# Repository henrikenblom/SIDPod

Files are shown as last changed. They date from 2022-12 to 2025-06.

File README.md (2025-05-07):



_The SIDPod is a PSID player for RP2040 microcontroller based boards, such as the
[Raspberry Pi Pico](https://www.raspberrypi.com/products/raspberry-pi-pico/) or the
[Solder Party RP2040 Stamp](https://www.solder.party/docs/rp2040-stamp/). Playback is based on the SID emulator found in
[Teensy-reSID](https://github.com/FrankBoesing/Teensy-reSID), which in turn is based on
[reSID](https://github.com/daglem/reSID)_

___

<!-- TOC -->
  * [Building](#building)
    * [Software](#software)
      * [Building from source](#building-from-source)
      * [Prebuilt binaries](#prebuilt-binaries)
    * [Hardware](#hardware)
      * [Construction](#construction)
      * [Power](#power)
      * [Bill of materials](#bill-of-materials)
  * [Using](#using)
    * [Finding music](#finding-music)
    * [Creating playlists](#creating-playlists)
    * [Adding music](#adding-music)
    * [Playback](#playback)
      * [Chip support](#chip-support)
      * [Playlist selection](#playlist-selection)
      * [Song selection](#song-selection)
    * [Visualization mode](#visualization-mode)
    * [Volume control](#volume-control)
    * [Pocket mode](#pocket-mode)
    * [Deep sleep](#deep-sleep)
  * [Beta disclaimer](#beta-disclaimer)
    * [General disclaimer](#general-disclaimer)
  * [What's on the horizon?](#whats-on-the-horizon)
<!-- TOC -->

## Building

### Software

#### Building from source

SIDPod requires both the [Raspberry Pi Pico SDK](https://github.com/raspberrypi/pico-sdk/) and the
[pico-extras](https://github.com/raspberrypi/pico-extras). Make sure to grab these and either put them next to the
SIDPod directory or, if you have them somewhere else, point the `PICO_SDK_PATH` and `PICO_EXTRAS_PATH` environment
variables to their respective location. You'll also need CMake on your path. If/when these prerequisites have been
satisfied, you're almost ready to run the `cmake` command to create the build directory and configure the build. One
last thing to do is to make sure the board type matches the one you have. By default, SIDPod builds for the Solder Party
RP2040 Stamp, which, for example, has a larger NAND flash than the more common Raspberry Pi Pico. Using a RP2040 Stamp
UF2 on a Pi Pico would most likely cause issues on the first run, as the flash will get formatted, **using board
specific settings**, if no readable FAT filesystem is found on it. Changing board type can either be done by modifying
the `PICO_BOARD` variable in [CMakeLists.txt](CMakeLists.txt) or by setting the `PICO_BOARD` environment variable before
running the `cmake` commands. The correct value for the Raspberry Pi Pico is 'pico'. Once this is done, the build is
configured by running:

`cmake -B cmake-build-debug`

Alternatively, if you have [Ninja](https://ninja-build.org/) installed, you can save a few seconds of your valuable time
by instead running:

`cmake -G Ninja -B cmake-build-debug`

Then, to build the _SIDPod.uf2_ binary, issue:

`cmake --build cmake-build-debug --target all`

Once the build finishes, just follow the official instructions for loading a UF2 binary onto the board. For Raspberry Pi
Pico you hold down the _BOOTSEL_ button when you plug it in and then copy _SIDPod.uf2_ to it, once it appears as a
drive named _RPI-RP2_. For some other types of boards, such as the Solder Party RP2040 Stamp, this mode is activated by
double-clicking the reset button.

Also note that if you're running macOS, copying using Finder might fail with this
error: _The operation can’t be completed because an unexpected error occurred (error code 100093)._
If this is the case, fire up the 'ol terminal and do:

`cp cmake-build-debug/SIDPod.uf2 /Volumes/RPI-RP2`

#### Prebuilt binaries

To get a jump start you can also grab the [prebuilt binaries](https://github.com/henrikenblom/SIDPod/releases/latest).
There are two versions, one for the Solder Party RP2040 Stamp and one for the Raspberry Pi Pico.

### Hardware

#### Construction

Since the main goal is to make a portable player, the actual build and design is up to you, the maker. My current
prototype is built inside a 3-AA battery box I had lying around, using a Solder Party RP2040 Stamp and a 3.7V 150mAh
LiPo battery. However, the breadboard design I'm using for development, based on a Raspberry Pi Pico H, looks like this:

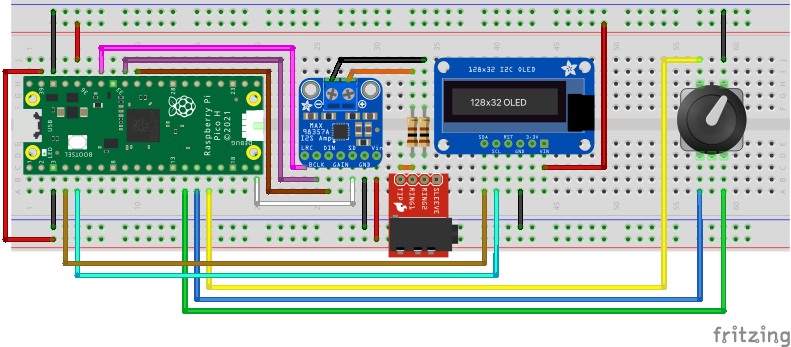
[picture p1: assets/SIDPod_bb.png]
  
_The breadboard schematics._

In reality, the development breadboard looks a bit different. I use a dual lane breadboard and connect to the SIDPod
Pico board via a [Picoprobe](https://github.com/raspberrypi/picoprobe), for debugging and a less painful development
process.

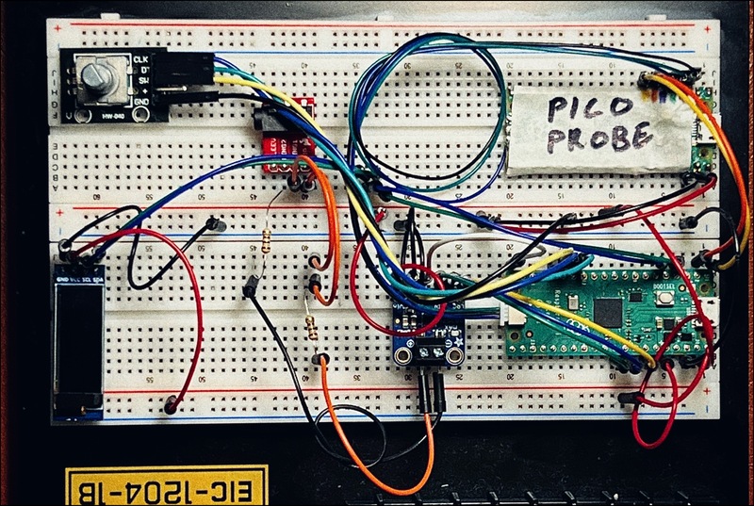
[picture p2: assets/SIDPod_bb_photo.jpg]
  
_The development breadboard setup._

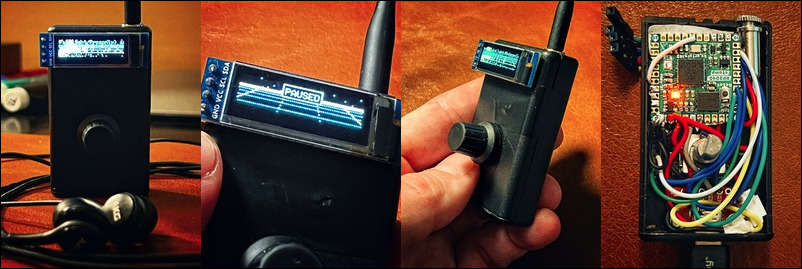
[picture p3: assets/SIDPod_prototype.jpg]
  
_The working prototype. Please excuse the soldering. I'm a lover, not a solderer. 😜_

#### Power

The main advantage of the Solder Party RP2040 Stamp, besides its size, is the onboard LiPo charger. This removes some
complexity and saves space when moving beyond the breadboard design. Many RP2040 projects can easily run off the power
provided from the host computer over the built-in USB port. The SIDPod however, will enter a special USB device state
and start to mimic a USB mass storage device once connected to a computer. [More on that here](#adding-music). This
poses a problem, if you actually want to use it for what it's designed for - to play PSIDs. That problem can easily be
solved by powering it from any power source connected to the _VSYS_ pin. That power source can be anything from a 3.7V
LiPo battery to a separate USB breakout bord, with the breakout boards _VBUS_ connected to _VSYS_ on the Pico Board and
the breakout board GND connector connected to any GND on the Pico Board. In my development breadboard setup I power the
SIDPod Pico Board from the Picoprobe Pico Board. In the next section I've listed the components needed for a few
different options:

#### Bill of materials

_Option 1 - Using a Solder Party RP2040 Stamp (the prototype setup):_

- 1 x [Solder Party RP2040 Stamp](https://www.electrokit.com/en/product/rp2040-stamp/)
- 1 x [Adafruit I2S 3W Class D Amp - MAX98357A](https://www.electrokit.com/en/product/forstarkare-klass-d-3w-mono-i2s/)
- 1 x [LCD OLED 0.91″ 128x32px I2C](https://www.electrokit.com/en/product/lcd-oled-0-91-128x32px-i2c/)
- 1 x 3.5mm stereo jack
- 1 x [Rotary encoder w switch](https://www.electrokit.com/en/product/rotary-encoder-module/)
- 2 x [100Ω resistor](https://www.electrokit.com/en/product/resistor-1w-5-100ohm-100r/)
- 1 x [Battery LiPo 3.7V 150mAh](https://www.electrokit.com/en/product/batteri-lipo-3-7v-150mah/)

_Option 2 - Using a Raspberry Pi Pico (the breadboard setup):_

- 1 x [Adafruit I2S 3W Class D Amp - MAX98357A](https://www.electrokit.com/en/product/forstarkare-klass-d-3w-mono-i2s/)
- 1 x [LCD OLED 0.91″ 128x32px I2C](https://www.electrokit.com/en/product/lcd-oled-0-91-128x32px-i2c/)
- 1 x [3.5mm stereo jack](https://www.electrokit.com/en/product/3-5mm-jack-breakout-2/)
- 1 x [Rotary encoder w switch](https://www.electrokit.com/en/product/rotary-encoder-module/)
- 2 x [100Ω resistor](https://www.electrokit.com/en/product/resistor-1w-5-100ohm-100r/)

_Option 2a - Add a Raspberry Pi Pico with Picoprobe, for debugging, binary upload and power through VSYS:_

- 2 x [Raspberry Pi Pico H](https://www.electrokit.com/en/product/raspberry-pi-pico-h/)

_Option 2b - Power the Raspberry Pi Pico through a USB breakout board:_

- 1 x [Raspberry Pi Pico H](https://www.electrokit.com/en/product/raspberry-pi-pico-h/)
- 1 x [Breakout board USB-C](https://www.electrokit.com/en/product/anslutningskort-usb-c/)

## Using

To keep the construction as simple as possible I tried to minimize the number of physical controls, and a rotary encoder
with a built-in push button provides enough versatility to cater to every possible use case of this rather minimal
design. Therefore, controls are both contextual and pattern driven.

### Finding music

The [SID or Sound Interface Device](https://en.wikipedia.org/wiki/MOS_Technology_6581), which this player does a
rudimentary emulation of, was a component in the world's most popular home computer, the
[Commodore 64](https://en.wikipedia.org/wiki/Commodore_64). Due to its legendary status and, to this day, very active
community, there's no shortage of SID files to fill your SIDPod with. The most complete collection is the
[High Voltage SID Collection](https://www.hvsc.c64.org/). It has everything, from cult classics by the legendary Jeroen
Tel to contemporary pieces by Kamil Wolnikowski, aka Jammer. Download the full archive and use one of the SID players
referenced on that page to find the music you like. The collection contains both PSIDs and RSIDs. Most PSIDs are
playable and with the introduction of reSID, (version 2.0beta and later) some RSIDs are playable. However, full
compatibility is not guaranteed yet. _This is being worked on though._

### Creating playlists

With the introduction of version 2.0beta, **music must be put in playlists**. And the definition of a playlist is a
folder with at least one PSID in it. Furthermore, to avoid out of memory errors, the maximum number of PSIDs in a
playlist is restricted to 256. And the number of playlists is limited to 256 as well. This means that the maximum number
of PSIDs is 65536. Coincidentally, the memory size of our favorite 8-bit home computer. ❤️

_As you may have figured out, this many PSIDs would never fit on the internal flash. They will however fit on a
standard size SD card, which is something that will be supported when SIDPod 2.0 is out of beta._

### Adding music

The SIDPod doubles as a USB mass storage device, which means that if you plug it in to your computer it will show up as
a regular, FAT-formatted drive. This means that adding and removing PSIDs is as easy as copying or deleting files. There
are a few caveats though:

- Since version 2.0beta PSIDs must be put in folders. As mentioned above.
- Use it with moderation. [FatFs](http://elm-chan.org/fsw/ff/00index_e.html) doesn't have any
  [wear levelling algorithm](https://en.wikipedia.org/wiki/Wear_leveling), and NAND flash storage wears out faster than
  regular flash drives. Note though that this only goes for write operations. Reading is totally harmless.
- It's slower than you're probably used to. This is due to several factors. One being that flash memory blocks needs to
  be erased before new data can be written to them.

While the SIDPod is connected, the screen shows flickering bars. Don't be alarmed. This is a feature, not a bug. In
fact, it's a reference to the C64 - those who know, know.

### Playback

#### Chip support

Since the introduction of version 2.0beta, the SIDPod supports both the MOS 6581 and MOS 8580 chip models, and up to
three SID chips. There's no need to worry about which chip is used in the PSID file, or how many, as the SIDPod will
automatically detect this and set up the emulation accordingly.

_Disclaimer: Some 3-SID songs are a bit too much for the poor SIDPod, resulting in partial stutter when the filters are
active. Unless you overclock it! Currently, the clock speed is set to 200MHz, which is the highest officially supported
setting. For songs like Melbourne Shuffle by Jammer, you need to stretch this all the way up to 260. Which might damage
your microcontroller!_

#### Playlist selection



Once you've added some funky tunes and **safely disconnected** the SIDPod it presents the playlists. In alphabetical
order. The controls in this mode are:

- Scroll through the list by turning the encoder.
- Single-clicking enters the selected playlist.

If you've started a song, as described in the next section, the relevant playlist is decorated with an animated spectrum
analyser symbol. When a song is paused, the animation is paused as well.

#### Song selection



Once you've entered a playlist, the screen shows the songs in that playlist. Also in alphabetical order. There's also a
*<< Return* entry at the top. Use it to navigate back to the playlist selection view. The controls in this mode are:

- Scroll through the list by turning the encoder.
- Single-clicking plays the selected song and enters a very retro-fancy visualization mode.
- Double-clicking plays or pauses the selected song but keeps the playlist mode.
- Double-clicking in visualization mode pauses playback and displays a pause notification on screen.

The currently selected song is decorated with a traditional play symbol and the currently playing song is decorated with
an animated spectrum analyser symbol. When a song is paused, the animation is paused as well.

If a song gets crossed out when you're trying to play it, it means that it's either corrupt or uses a combination of
opcodes that have caused the song loading routine to enter an infinite loop and seemingly hang. This is very rare for
PSIDs, but unfortunately a little more common for RSIDs. _As mentioned above, a fix for this is being worked on._

### Visualization mode



This is the mode that shows the animated spectrum analyser. _Plus a few other effects._ The controls in this mode are:

- Single-clicking returns to the song selection view.
- Double-clicking plays or pauses the selected song but keeps the visualization mode.
- Turning the encoder adjusts the volume. See below.

### Volume control



This control is only available from the visualization mode and is activated by rotating the encoder. Turn the encoder
clockwise to increase the volume and counter-clockwise to decrease it. The current volume is displayed on screen as long
as the encoder is being turned. Plus 400ms after the last turn.

_Warning! With the current implementation the overall sound volume has increased since the first version. Be mindful of
this, if you're using headphones._

### Pocket mode

In this mode the screen is turned off, as well as the regular controls. Playback is still active though, which makes it
perfect for when you're out and about. To enter this mode, simply hold the button pressed until the screen goes black.
This takes exactly one second. Be careful not to hold it for too long, as this will put the SIDPod to sleep. More on
that in the next section. To get out of pocket mode, simply double-click, and it will return to whatever mode you were
in before entering pocket mode.

### Deep sleep

This mode is as close as you can get to turning the SIDPod off. As with pocket mode, all regular controls are disabled.
Additionally, playback is stopped, as well as USB device clocks. In fact, in this mode, even both processor cores are
stopped, meaning that the power consumption is next to nothing. To enter deep sleep, press the button for more than two
and a half second. To get out, hold the button until the SIDPod splash appears.

## Beta disclaimer

This is a beta version of the SIDPod. While it has been tested thoroughly, there are still some bugs and issues that
need to be worked out. And the entire code base would benefit from some cleanup and pattern alignment.

### General disclaimer

Even though I am a professional software engineer, I am a novice and a hobbyist when it comes to both hardware and C/C++
development. So there's a good chance that I have made more than a few mistakes. If you find any, please let me know, by
opening an issue on GitHub. I'll be happy to fix them and learn from them. Hopefully in a timely manner.

## What's on the horizon?

- Support for SD cards. This will allow you to store a lot more music than the internal flash can handle.
- Pi Pico 2 support. This will improve performance and playback quality. Potentially, this could allow for builtin
Bluetooth A2DP support. For Pi Pico 2W boards.
- "SIDPod Buddy" support. The SIDPod Buddy is an ESP32 based device that allows you to control the SIDPod using a
Cirque TM023023 Trackpad. Additionally, it provides Bluetooth A2DP support, which means that you can stream music to any
Bluetooth enabled speaker.
- A custom PCB, incorporating all the components needed to make a fully functional SIDPod. With SIDPod Buddy support.

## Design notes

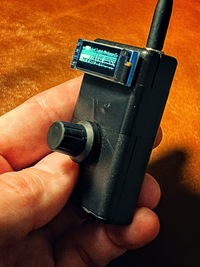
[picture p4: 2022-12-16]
assets/SIDPod_photo_4.jpg

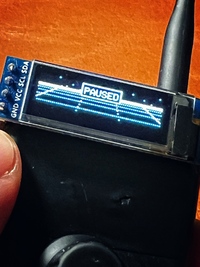
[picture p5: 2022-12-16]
assets/SIDPod_photo_2.jpg

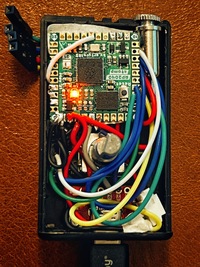
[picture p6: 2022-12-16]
assets/SIDPod_photo_3.jpg

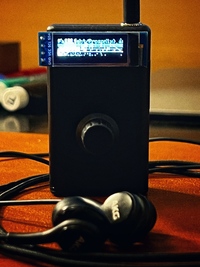
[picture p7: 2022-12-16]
assets/SIDPod_photo_1.jpg

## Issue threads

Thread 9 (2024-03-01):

Stuck on PAUSED

LouDnl, 2024-03-01:
Hi there, great project! I have an issue where the device will never leave PAUSED.
Everything seems to work and be connected correctly, display works, rotary works, can set volume choose song etc.
But the double click seems to not do anything

I am using your pre compiled PICO binary.

LouDnl, 2024-03-01:
Its not the doubleclick I think, it just will not play any sid. Locked specifically for psid files. They show and I can select them, but then its paused immediately

LouDnl, 2024-03-01:
After compiling myself it unfortunately still did not work.
Tried debugging with gdb but was missing debug symbols. Recompiled with debugsymbols and used the elf with gdb but didnt works, forgot to flash the new compiled version.

As soon as I flashed the compiled bin and started gdb everything worked without doing anything 🤷🏻‍♂️

Still don't know what fixed it 🤣

LouDnl, 2024-03-01:
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

MaoCiao7, 2025-04-24:
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

Would you please share your forked binary? :) I tried the prebuilt from henrikenblom, but have the same problems.

henrikenblom, 2025-04-24:
Hey there! First of all, it warms my heart that people are building their own SIDPods! Secondly, I apologize for my lack of activity and engagement. And lastly, I decided to give this project some love, by:

- fixing bugs
- integrating reSID (with tripple-SID support)
- adding SD-card support
- adding playlist support

This all lives in the 'resid' branch (please note that the I2S pins for the display is different in that branch, if you decide to try it out). But since you're here due to bugs, I'll try to find some time in the next few days to fix the most critical ones in the master branch as well. And I'll make sure to keep you posted.

henrikenblom, 2025-05-07:
Hello again, @MaoCiao7 et al. I've put together a pre-release - version 2.0beta. Give it a try!
https://github.com/henrikenblom/SIDPod/releases

MaoCiao7, 2025-05-08:
Hi @henrikenblom,

thank you very much! I've only been able to test a little so far, but it works much better now! Music is coming to the headphones and the navigation is also working. However, only 2 or 3 PSIDs (out of about 10) that I randomly selected for the test also had sound. Maybe I was just unlucky here in terms of compatibility. When there was sound, it was unfortunately not flawless. It seems that not all channels are equally loud and the sounds are generally distorted. Slow CLK issue? For the not working files, the small play animation appears next to the file name in the song selection screen, but otherwise it remains completely silent. In the Visualization Screen, the visual effects are also missing for those files, in line with the non-existent music, but the text is displayed.
I´ll try more songs as soon as possible.

henrikenblom, 2025-05-09:
> When there was sound, it was unfortunately not flawless. It seems that not all channels are equally loud and the sounds are generally distorted. Slow CLK issue?

This sounds to me like an issue with the amplifier. The hardware setup I've described is a workaround for the lack of I2S headphone amplification breakout boards on the market. - The two resistors between the amp and the headphones are put there to compensate for the difference in impedance specification between headphones and "regular" speakers. But this is basically a very crude hardware hack, that might not work for all headphones. So, could you try to remove the resistors and use a small 2-5W rated speaker instead, to see if the problem persists? If you're using the exact amp model described in the setup, there's also a gain setting to play around with.

> However, only 2 or 3 PSIDs (out of about 10) that I randomly selected for the test also had sound.

Could you post the names, (and artists) of some of the PSIDs that didn't work? So that I can check wether it's due to any of the known issues.

MaoCiao7, 2025-05-09:
you were right, the distortion was caused by my headphones. I tried my other headset and it sounds clean now. songs with no sound are eg. from Chris Huelsbeck, To be on top & Being boild.

henrikenblom, 2025-05-09:
My suspicions regarding Ikari Warriors were correct. And I've merged a small fix for it. It turned out to be an unfortunate, and somewhat exotic, combination of a high CIA Timer value and NTSC. So even if it would have played, the tempo would have been completely off.

New release here: https://github.com/henrikenblom/SIDPod/releases/tag/v2.0.1beta

Btw, I'm closing this issue now, since it no longer has anything to do with the original one. But feel free to open new one's at any time.

Closed 2025-05-09.

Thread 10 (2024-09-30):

Sidpod building

n2hyo, 2024-09-30:
Hello there, i have build a sidpod on a breadboard and it seems to work but i am not getting any audio output
when i select a song and the click on it, it goes paused another press goes out of pause, i never get any indication
that the song is actually playing and by the way i am using the prebuild image. Does a pal/ntsc sid have any bearing
on ability to be played?

Thank You,
Mike Russell

Neril, 2024-10-10:
@n2hyo

I'm not an author / contributor to this project but coincidentally this week I successfully managed to get SIDPod working on my own breadboard. Given your issue was reported last week, maybe I can help.

Just a random punt, but if you're getting a play indication next to your SID files and/or wave forms being shown in the visualiser, I think the issue must lie with your amp / amp wiring, or downstream of that.

Feel free to post a picture / video of your board and tag me and if I see it then I'll compare it to mine while I still have it assembled.

n2hyo, 2024-10-10:
Hello Neril, no i never get the wave forms in thew visualizer, i know it will only play psid files which i think i have but may be the problem. I have attached the file i am trying to play maybe you can try it and maybe send me back a sid file you know works on yours.

Thanks Mike
[Ashes_to_Ashes.zip](https://github.com/user-attachments/files/17334544/Ashes_to_Ashes.zip)

Neril, 2024-10-10:
The ashes to ashes entry doesn't show up in the SIDPod list for me after I add the file. I think this is likely because the SIDPod code recognises it as something it can't play. I'm not immediately sure why - it has the PSID header (first 4 bytes), but there's a long and storied history around SID files and versioning I've only scratched the surface of, so it may be a variant of the format it doesn't recognise / can't handle.

I've been getting my .sid files out of HVSC_81-all-of-them.7z from https://www.hvsc.c64.org/downloads
I notice it contains Ashes_to_Ashes.sid under MUSICIANS/L/Linus, and it looks the same as the version you attached (i.e. same file size). A_mouse_me_kitty.sid from the same directory worked for me, though. I've personally been testing with Wizball.sid (Gallway_Martin) and most of Rob Hubbard's work (e.g. The Master of Magic) which work well besides a few volume issues.

It's a long shot, but I initially had problems getting playback to start initially. I tracked it down and wrote a long ramble about it here https://github.com/henrikenblom/SIDPod/issues/9

n2hyo, 2024-10-11:
So i loaded that song you mentioned and when i plug the pico into usb port the

https://github.com/user-attachments/assets/c2af47bf-28c7-407e-bdbf-805afa5f97cf

screen does this, is this supposed to be playing?

Neril, 2024-10-12:
Those lines are what SIDPod displays when it has noticed it is plugged into a PC, so it's emulating a USB flash drive and ready to accept SID files. What you are seeing is the "flashing bars" described at https://github.com/henrikenblom/SIDPod?tab=readme-ov-file#adding-music - reminiscent of a game C64 loading screen.

To get SIDPod into a mode where it will play tunes it needs to be _not_ connected to a PC. This is most easily achieved by taking your USB cable out of your PC and putting it into a spare phone charger or USB battery. The SIDPod will boot up, showing the SIDPod logo like before, but then showing the list of songs you've stored on the device instead of the flashing bars. Playing music is achieved via steps documented at https://github.com/henrikenblom/SIDPod?tab=readme-ov-file#playback

TBH, I thought you'd got this far from your original comment above.

Closed 2025-05-12.

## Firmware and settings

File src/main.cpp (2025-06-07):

// ReSharper disable once CppUnusedIncludeDirective
#include <hardware/clocks.h>
#include <device/usbd.h>
#include <hardware/watchdog.h>
#include "platform_config.h"
#include "audio/SIDPlayer.h"
#include "UI.h"
#include "System.h"
#include "Catalog.h"

using namespace std;

void buddyCallback();

void runPossibleSecondWakeUp() {
    if (watchdog_caused_reboot()) {
        int c = 0;
        while (c++ < LONG_PRESS_DURATION_MS) {
            if (gpio_get(SWITCH_PIN)) {
                System::goDormant();
            }
            busy_wait_ms(1);
        }
    }
}

bool awaitButtonRelease() {
    int c = 0;
    while (!gpio_get(SWITCH_PIN)) {
        busy_wait_ms(1);
        c++;
    }
    return c >= LONG_PRESS_DURATION_MS;
}

#if USE_BUDDY
void initUart() {
    uart_init(UART_ID, 2400);

    gpio_set_function(UART_TX_PIN, UART_FUNCSEL_NUM(UART_ID, UART_TX_PIN));
    gpio_set_function(UART_RX_PIN, UART_FUNCSEL_NUM(UART_ID, UART_RX_PIN));

    uart_set_baudrate(UART_ID, BAUD_RATE);
    uart_set_hw_flow(UART_ID, false, false);
    uart_set_format(UART_ID, DATA_BITS, STOP_BITS, PARITY);
    uart_set_fifo_enabled(UART_ID, true);

    irq_set_exclusive_handler(UART1_IRQ, buddyCallback);
    irq_set_enabled(UART1_IRQ, true);

    uart_set_irq_enables(UART_ID, true, false);
}
#endif

[[noreturn]] int main() {
    set_sys_clock_khz(CLOCK_SPEED_KHZ, true);
    stdio_init_all();
#if USE_BUDDY
    initUart();
#endif
    UI::initUI();
    runPossibleSecondWakeUp();
    UI::screenOn();
    UI::showSplash();
    UI::screenshotToPBM();
    const bool quickStart = awaitButtonRelease();
    System::enableUsb();
    if (!System::usbConnected()) {
        System::prepareFilesystem();
        UI::start(quickStart);
        SIDPlayer::initAudio();
    }
    while (true) {
        UI::updateUI();
    }
}
#pragma clang diagnostic pop

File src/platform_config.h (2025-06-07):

#pragma once

#define IS_BIT_SET(value, bit) (((value) & (1 << (bit))) != 0)

#ifndef USE_SDCARD
#include "hardware/flash.h"

#ifdef SOLDERPARTY_RP2040_STAMP
#define FLASH_STORAGE_BYTES (7552 * 1024)
#endif
#ifdef RASPBERRYPI_PICO
#define FLASH_STORAGE_BYTES                 (1408 * 1024)
#endif

#define SECTOR_COUNT                        (FLASH_STORAGE_BYTES / FLASH_SECTOR_SIZE)
#define FLASH_BASE_ADDR                     (PICO_FLASH_SIZE_BYTES - FLASH_STORAGE_BYTES)
#define FLASH_MMAP_ADDR                     (XIP_BASE + FLASH_BASE_ADDR)

#endif

#define AIRCR_Register                      (*((volatile uint32_t*)(PPB_BASE + 0x0ED0C)))
#define SYSRESETREQ                         0x5FA0004

#if defined SYS_CLK_MHZ && SYS_CLK_MHZ == 200
#define CLOCK_SPEED_KHZ                     200000
#else
#define CLOCK_SPEED_KHZ                     125000
#endif

#define SYNC_INTERVAL_MS                    40

#define BOARD_TUD_RHPORT                    0

#ifndef HW_USB_VID
#define HW_USB_VID                          (0x2E8A)
#endif
#ifndef HW_USB_PID
#define HW_USB_PID                          (0x0006)
#endif

#define FS_LABEL                            "SIDPOD"

#define AUDIO_RENDERING_STARTED_FIFO_FLAG   124

#define PSID_HEADER_SIZE                    ((uint8_t) 0x7e)
#define PSID_MINIMAL_HEADER_SIZE            ((uint8_t) 0x56)
#define PSID_ID                             0x50534944
#define RSID_ID                             0x52534944
#define SID_LOAD_BUFFER_SIZE                ((int) 256)
#define CPU_JSR_WATCHDOG_ABORT_LIMIT        0xffff

#define SAMPLE_RATE                         ((uint32_t)44100)
#define MAX_SAMPLES_PER_BUFFER              880
#define PAL_SPEED_FACTOR                    1.0f
#define NTSC_SPEED_FACTOR                   0.96f
#define NTSC_CPU_FREQUENCY                  1022730
#define PAL_CPU_FREQUENCY                   985248

#define AMP_CONTROL_PIN                     15

#define VOLUME_STEPS                        48
#define INITIAL_VOLUME                      16
#define SONG_SKIP_TIME_MS                   5000

#define I2C_BAUDRATE                        400000
#define DISPLAY_I2C_BLOCK                   i2c1
#define DISPLAY_GPIO_BASE_PIN               2
#define DISPLAY_EXTERNAL_VCC                0
#define DISPLAY_WIDTH                       128
#define DISPLAY_HEIGHT                      32
#define DISPLAY_X_CENTER                    (DISPLAY_WIDTH / 2)
#define DISPLAY_Y_CENTER                    (DISPLAY_HEIGHT / 2)
#define DISPLAY_I2C_ADDRESS                 0x3C

#define UART_ID                             uart1
#define BAUD_RATE                           115200
#define UART_TX_PIN                         8
#define UART_RX_PIN                         9
#define DATA_BITS                           8
#define STOP_BITS                           1
#define PARITY                              UART_PARITY_NONE

#define DISPLAY_STATE_CHANGE_DELAY_MS       500
#define FONT_WIDTH                          6
#define FONT_HEIGHT                         8
#define LIST_WINDOW_SIZE                    (size_t)((DISPLAY_HEIGHT / FONT_HEIGHT) - 1)
#define MAX_PATH_LENGTH                     FF_LFN_BUF + FF_SFN_BUF + 1
#define MAX_LIST_ENTRIES                    256
#define RETURN_ENTRY_TITLE                  "<< Return"
#define SONG_LIST_LEFT_MARGIN               6
#define NOW_PLAYING_SYMBOL_HEIGHT           5
#define NOW_PLAYING_SYMBOL_ANIMATION_SPEED  ((float) 0.1)
#define DEFAULT_SPECTRUM_COMPENSATION       ((double ) 0.00002)
#define LINE_LEVEL_SPECTRUM_COMPENSATION    ((double ) 0.00000003)
#define HORIZONTAL_LANDSCAPE_LINES          (DISPLAY_HEIGHT / 2)
#define SOUND_SPRITE_COUNT                  (DISPLAY_HEIGHT * DISPLAY_WIDTH / 8)
#define ROUND_SPRITE_COUNT                  (DISPLAY_WIDTH / 2)
#define STARFIELD_SPRITE_COUNT              (int (DISPLAY_WIDTH * 3))
#define SPECTRUM_SCENE_DURATION_MS          62000
#define ALTERNATIVE_SCENE_DURATION          79000
#define STARFIELD_ACTIVE_AFTER              30000
#define END_SPHERE_SCENE_AFTER              35000
#define FROM_ALTERNATIVE_TRANSITION_DURATION       8600
#define SCROLL_LIMIT                        (-1000)
#define FFT_SAMPLES                         1000
#define LOW_FREQ_DOMINANCE_COMP_OFFSET      2
#define SIDPLAYER_STARTUP_GRACE_TIME        800
#define SONG_NUMBER_DISPLAY_DURATION        3000
#define SONG_NUMBER_SHOW_HIDE_DURATION      1000
#define SONG_NUMBER_DISPLAY_DELAY           1000

#define USER_CONTROLS_POLLRATE_MS           50

#if (!USE_BUDDY)
#define ENC_PIO                             pio1
#define ENC_SM                              1
#define ENC_BASE_PIN                        10
#endif

#define SWITCH_PIN                          12
#define DOUBLE_CLICK_SPEED_MS               250
#define LONG_PRESS_DURATION_MS              1000
#define DORMANT_ADDITIONAL_DURATION_MS      1500
#define VOLUME_CONTROL_DISPLAY_TIMEOUT      400
#define SPLASH_DISPLAY_DURATION             2000
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

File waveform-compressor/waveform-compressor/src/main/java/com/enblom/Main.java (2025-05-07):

package com.enblom;

import java.io.IOException;
import java.nio.file.Path;

public class Main {

  public static void main(String[] args) {
    Compressor compressor = new Compressor();
    try {
      var compressed =
          compressor.compress(
              Path.of(
                  "/Users/henblom/projects/github/henrikenblom/SIDPod/src/audio/reSID/wave6581_PST.cc"));
      for (int i = 0; i < 64; i++) {
        if (i % 16 == 0) {
          System.out.println();
        }
        System.out.print(String.format("0x%02x, ", compressed.values.get(i)));
      }
      System.out.println();
      System.out.println();
      System.out.println(compressed);
      for (int i = 0; i < 4096; i++) {
        if (i % 8 == 0) {
          System.out.print(String.format("\n/* 0x%03x: */  0x%02x, ", i, compressed.getValue(i)));
        } else {
          System.out.print(String.format("0x%02x, ", compressed.getValue(i)));
        }
      }
    } catch (IOException e) {
      e.printStackTrace();
    }
  }
}

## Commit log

2022-11-15 Add song selection using an encoder
2022-11-15 Fix broken USB connection handling
    Show raster bars when connected to host
    [UI.cpp, main.cpp]
2022-11-17 Avoid I2S external race conditions when switching songs
    [UI.cpp, main.cpp, sid.c]
2022-11-17 Increase song switch stability
    [UI.cpp]
2022-11-17 Reduce switch glitching
2022-11-18 Reset core1 on USB mount
    [main.cpp]
2022-11-18 Ignore i2c ack errors during flash writes
    [UI.cpp]
2022-11-18 Move the entire audio stack to core1
    Reset the entire machine on USB disconnect
    [UI.cpp, main.cpp]
2022-11-21 Use the AIRCR to request the post USB suspend reset
    [main.cpp]
2022-11-21 Reduce encoder read flakiness by using PIO
2022-11-21 Reduce memory footprint
    Fix tempo issue
2022-11-21 Revert CIA sync changes
    [main.cpp]
2022-11-21 Add TODO on something that needs to be fixed in order to reduce footprint
2022-11-22 Reduce PSIDCatalog footprint
2022-11-23 Add support for I2S amp shutdown/powerup
    Cleanup
2022-11-26 Trigger volume control by encoder
    Time limit volume control session
2022-11-26 Enable navigation to and from visualization of current song and list view
2022-11-26 Add power save functions
2022-11-27 Freeze pause screen to conserve power
2022-12-01 Make the Solderparty RP2040 Stamp the default config
    Decrease display sleep flakyness
2022-12-02 Sleep 250ms after display power state change to avoid timing issues
    [UI.cpp]
2022-12-04 Load SIDs directly from file
    Use a callback to solve timing issues during display power state change
    [DanceFloor.h, UI.cpp, platform_config.h]
2022-12-07 Fix a bug where the full flash capacity couldn't be used
    [UI.cpp]
2022-12-08 Increase FAT capacity
2022-12-08 Reduce footprint of PSIDCatalog
2022-12-09 Suppress high intensity frequency visualization
    Reduce footprint of dance floor sound sprites
2022-12-09 Reduce footprint of dance floor sound sprites
2022-12-09 Decorate the currently loaded entry with a note symbol
2022-12-10 Fix a bug where endless virtual CPU loops would cause SIDPlayer to hang
    Mark unplayable PSIDs
    [DanceFloor.h, UI.cpp, main.cpp]
2022-12-12 Increase display stability after returning from dormant
    [DanceFloor.h, UI.cpp, main.cpp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]
2022-12-13 Fix a user journey logic glitch
    Require doubleclick to enable screen and controls after longpress-lock
    [UI.cpp, platform_config.h]
2022-12-13 Fix race condition in dormant enter/exit logic
    [UI.cpp]
2022-12-13 Make USB/ADC work again after dormant return, by resetting all clocks
    [UI.cpp, main.cpp]
2022-12-14 Cleanup UI code by using an enum and switch statements instead of booleans
2022-12-14 Fix a bug where the SIDPod would crash if connected to USB when going out of dormant mode
    [UI.cpp]
2022-12-14 Add documentation resources
    [SIDPod.fzz]
2022-12-16 Remove the battery from the breadboard schematic
    [SIDPod.fzz]
2025-03-29 Enable filter, cleanup, fix visualization synch
    [C64.cpp, DanceFloor.h, platform_config.h]
2025-03-29 Enable external reSID filter, make volume control logarithmic
2025-03-30 Fix pause/load visualization functions
    [C64.cpp, DanceFloor.h, platform_config.h]
2025-03-30 Fix dormant mode, prepare battery measurement
    [UI.cpp, main.cpp, platform_config.h]
2025-03-31 Sort catalog, fix speed of CIA based SIDs, fix a few UI details
    [DanceFloor.h, UI.cpp, platform_config.h]
2025-04-03 Use the latest pico sdk cmake files, fix an error in CMakeLists.txt
    [platform_config.h]
2025-04-06 Show failed-dialog instead of paused on load failure. Slightly reduce memory usage.
    [DanceFloor.h, UI.cpp, platform_config.h]
2025-04-07 Fix speed identification and increase compatibility
    [C64.cpp, platform_config.h]
2025-04-08 Fix a bug where the second SID would get written to instead of lower ram, for single-SID songs.
    [C64.cpp]
2025-04-08 Improve timer handling
2025-04-09 Rename a few constants, fix a few bugs
    [C64.cpp, platform_config.h]
2025-04-09 Fix a bug where the volume of single-SID tunes couldn't be changed
    [C64.cpp]
2025-04-09 Remove unused code, fix a video standard misidentification error
    [C64.cpp, platform_config.h]
2025-04-09 Correct a temporary SID address calculation
    [C64.cpp]
2025-04-10 Read CIA1 timer A values with the correct endianess and make a rough sample count calculation
    [C64.cpp]
2025-04-10 Correct filter array size for 8580
    [platform_config.h]
2025-04-12 Make includes in filter more coherent
2025-04-12 Jam all waveform combo lookups into huge switch statements
    [Main.java]
2025-04-13 Reduce the memory footprint by rendering and mixing multi-SID output simultaneously
2025-04-13 Fix a few UI bugs
    [UI.cpp, platform_config.h]
2025-04-13 Skip the splash delay if the user already has kept the button pressed for the configured duration
    [UI.cpp, main.cpp, platform_config.h]
2025-04-14 Move interpolator setup to C64.cpp, so that it doesn't run every time a new SID is created
    [C64.cpp, platform_config.h]
2025-04-17 Read 'playlists' and PSIDs from and SPI attached sdcard, instead of internal flash
2025-04-17 Use an SPI connected SD card as backing storage in USB MSD mode
2025-04-17 Allow up to 256 entries per playlist, and show a short text to indicate loading
    [UI.cpp, platform_config.h]
2025-04-17 Use a DMA channel to shovel data into the visualization buffer
2025-04-17 Increase the volume steps and fix a volume bar length calculation flaw
    [UI.cpp, platform_config.h]
2025-04-17 Increase SPI baudrate
2025-04-18 Make sure DMA channels and interpolators are only configured once
2025-04-18 Fix a bug where the entire FFT buffer wouldn't get filled up
    [C64.cpp, platform_config.h]
2025-04-21 Use options flags to build with SIDPod buddy support. Fix an ancient volume control bug.
    [UI.cpp]
2025-04-22 Add BT device list
2025-04-23 Use the UART for all Buddy communication
2025-04-25 Fix a few connection related bugs
    [Buddy.cpp, Buddy.h, UI.cpp]
2025-04-26 Save last connected BT device
2025-04-26 Add song switching
2025-04-28 Add a 3D sphere scene, and fix state bugs
    [C64.cpp, DanceFloor.h, UI.cpp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]
2025-04-28 Fix a catalog bug. Tweak transitions and effects.
    [Buddy.cpp, DanceFloor.h, UI.cpp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]
2025-05-04 Fix a few bugs
    [hw_config.c]
2025-05-04 Do not destroy the filesystem pointer post mount
2025-05-09 Fix a bug where high CIA timer values, in combination with NTSC, resulted in too small audio buffers
    [C64.cpp, platform_config.h]
2025-05-11 Lower the SD card baud rate, to avoid write errors
    [hw_config.c]
2025-06-06 Prevent search functionality unless a supported state is active
    [Buddy.cpp, Buddy.h, UI.cpp]
2025-06-07 Fix a bug where access to a null playlist is attempted
    [UI.cpp]
2025-06-07 Replace finding with filtering
    [Buddy.cpp, Buddy.h]
2025-06-08 Change Buddy enable pin
